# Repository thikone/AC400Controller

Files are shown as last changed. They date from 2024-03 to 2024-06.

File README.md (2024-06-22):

# AC400Controller
Replacement controller board for Record Power AC400 air filtering system.

Original board has very simplictic power supply that tends to overheat and burn that makes the use of the device hindered or not possible.

This is Arduino based drop-in replacement board that doesn't have this problem and also allows customizations.

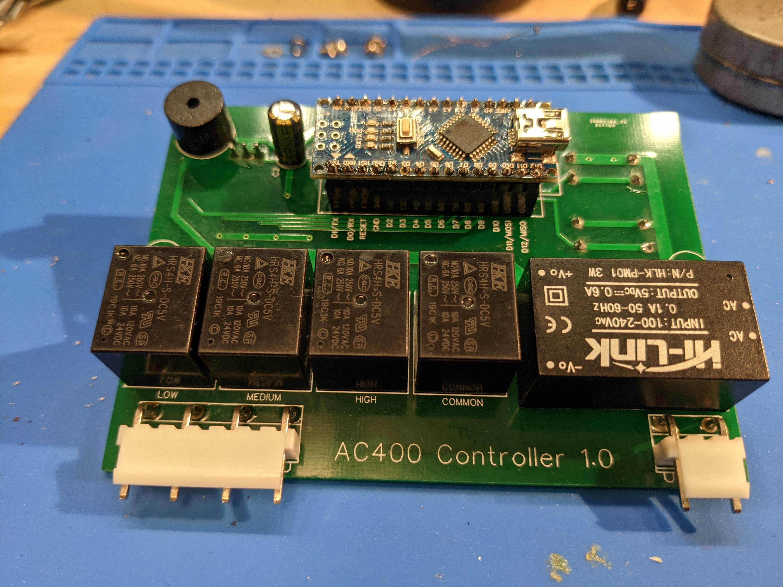
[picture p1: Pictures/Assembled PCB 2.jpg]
Assembled PCB


Ready for installation to Record Power AC400 air filtration unit:

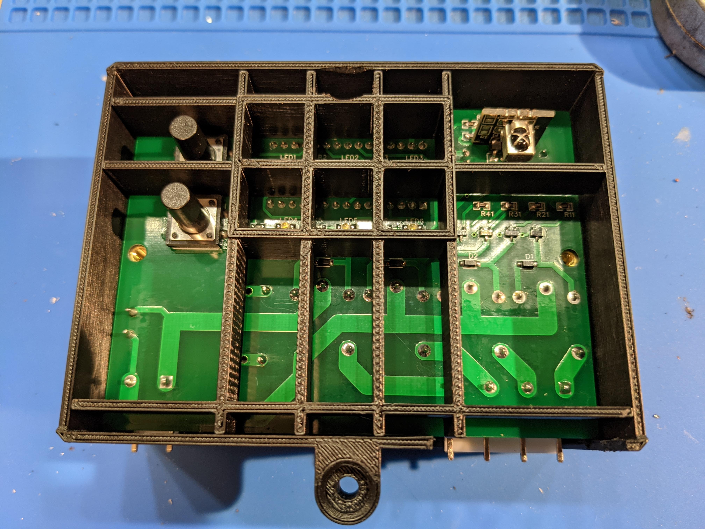
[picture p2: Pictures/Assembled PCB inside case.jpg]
Assembled PCB in the case Assembled PCB in 3D printed case


The PCB and Schematic `.json` files can be opened and viewed with EasyEDA [online](https://easyeda.com/)

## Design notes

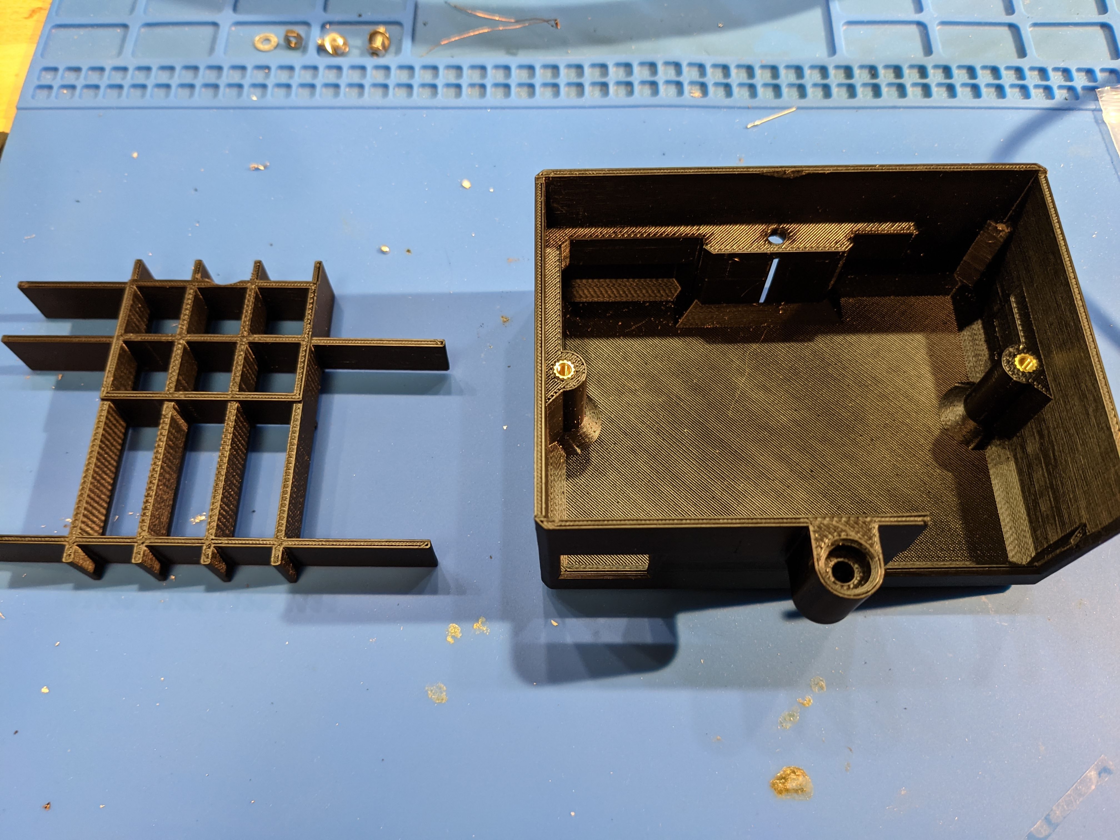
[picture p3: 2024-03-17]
Pictures/Case and grid.jpg

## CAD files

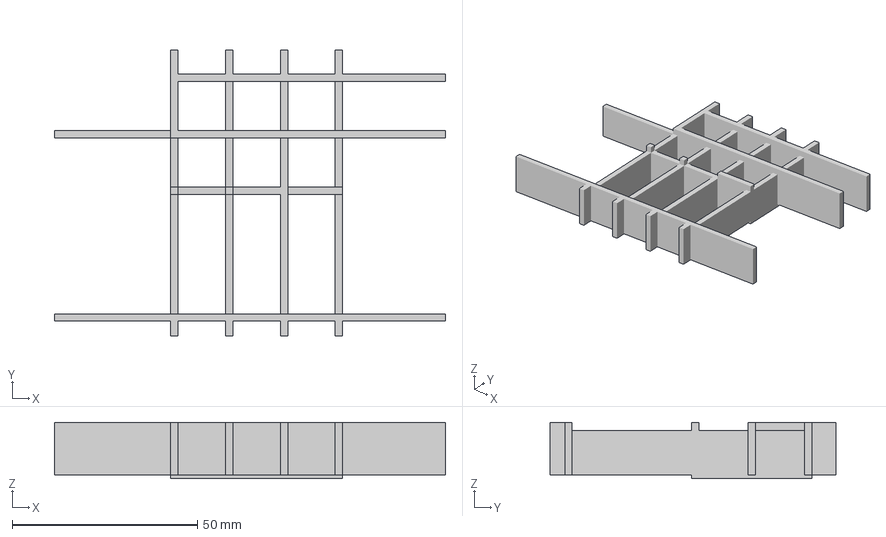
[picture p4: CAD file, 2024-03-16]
Cover/Grid v6.3mf
105.5 x 77.2 x 15.2 mm

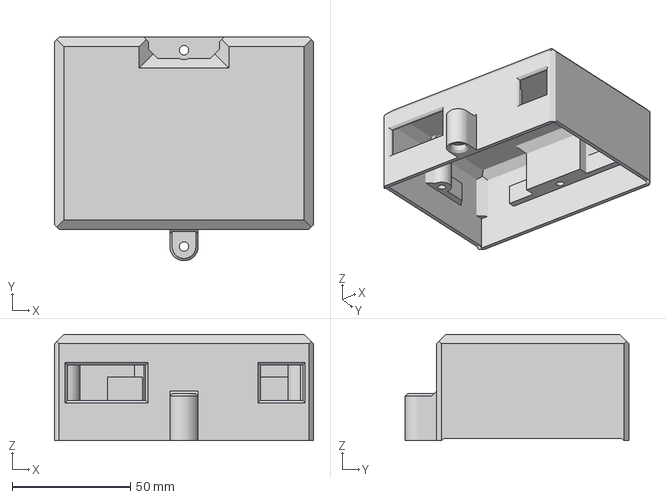
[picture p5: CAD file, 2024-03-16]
Cover/Case v6.3mf
109.5 x 94.5 x 45.0 mm

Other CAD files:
Cover/AC400 Cover v6.f3d
Cover/Case v6.stl
Cover/Grid v6.stl

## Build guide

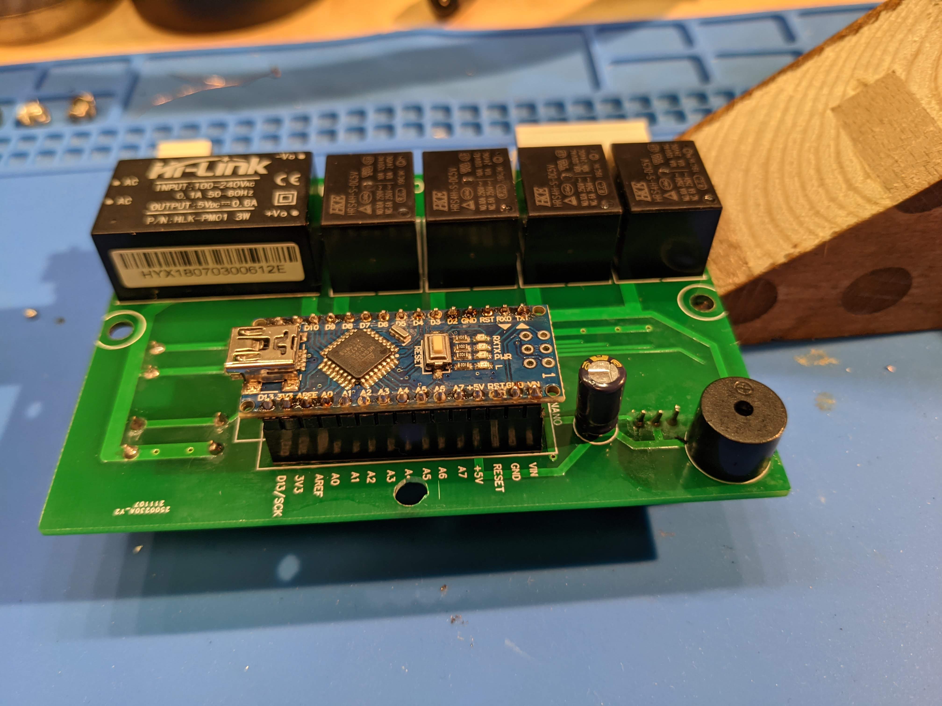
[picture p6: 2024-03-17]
Pictures/Assembled PCB 1.jpg

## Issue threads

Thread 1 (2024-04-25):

Question: Does the lack of fuse matter?

dturner, 2024-04-25:
I'm in the process of building this board and I noticed that the manufacturer's original board has a fuse next to the 240V input, this new design doesn't. Just interested to know whether it was a conscious decision to not include a fuse on this new board design?

Looking at the [specs for the machine](https://www.scosarg.com/record-ac400-2-stage-air-filter-free-delivery), the motor is 120W so at 240V that's a draw of 0.5A. Would it be worth changing the wall plug fuse to something lower, say 3A?

Slightly concerned that if a short were to occur, or the fan motor develop a fault, there could be a significant heat build up / fire risk.

thikone, 2024-04-26:
The board that came inside my machine does not have a fuse on it. The fuse is mounted on the panel and can be replaced from outside without disassembly of the unit.

I think there are several different boards that can be found in these machines. So it is totally possible that what I have might not be what you have.

So yes, there is no fuse on this replacement board. But it does make sense to have one somewhere. Perhaps you can mount it on outside panel if you don't have it there already.

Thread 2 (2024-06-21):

How to view schematic files?

matonb, 2024-06-21:
I tried uploading the the files in the schematic folder to https://www.altium.com/viewer/ but that didn't work

thikone, 2024-06-21:
Please use EasyEDA. Create a new project and open .json file.

I don't know whether Altium export of EasyEDA can be used in Altium online viewer.
EasyEDA is free and runs the browser.

Closed 2024-06-22.

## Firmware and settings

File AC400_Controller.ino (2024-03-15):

/*********************************************************************
Replacement controller board for Record Power AC400 air filtering system.

Requires:
  IRLremote (https://github.com/NicoHood/IRLremote)
Arduino standard libraries:
  EEPROM
  SoftwareSerial
*********************************************************************/

#include <IRLremote.h>

#define LED_PIN     13
#define IR_PIN       2
#define BEEP_PIN     5
#define KEY_ON_PIN   3
#define KEY_OFF_PIN  4
#define SPEED_ZERO_PIN 5
#define SPEED_LOW_PIN 6
#define SPEED_MEDIUM_PIN 7
#define SPEED_HIGH_PIN 8
#define SPEED_COMMON_PIN 9

#define LED_LOW_PIN A0
#define LED_MEDIUM_PIN A1
#define LED_HIGH_PIN A2
#define LED_ONE_PIN A5
#define LED_TWO_PIN A4
#define LED_THREE_PIN A3

#define RELAY_OFF LOW
#define RELAY_ON HIGH
#define KEY_ADDRESS 0xFF00
#define KEY_OFF_IR  0x90
#define KEY_ON_IR   0x30
#define KEY_TIME_IR 0xA0

#define SPEED_OFF 0
#define SPEED_LOW 1
#define SPEED_MEDIUM 2
#define SPEED_HIGH 3

#define AUTO_OFF 0
#define AUTO_ONE 1
#define AUTO_TWO 2
#define AUTO_THREE 3
#define AUTO_ONE_DURATION 3600000
#define AUTO_TWO_DURATION 7200000
#define AUTO_THREE_DURATION 14400000
//#define AUTO_ONE_DURATION 10000
//#define AUTO_TWO_DURATION 20000
//#define AUTO_THREE_DURATION 40000


CNec IRLremote;

int speed = SPEED_OFF;
int auto_off = AUTO_OFF;
unsigned long lastAutoTime;
unsigned long auto_delay;

int buttonState[2] = { LOW, LOW };       // the current reading from the input pin
int lastButtonState[2] = { LOW, LOW };   // the previous reading from the input pin
unsigned long lastDebounceTime[2] = { 0, 0 };  // the last time the output pin was toggled
unsigned long debounceDelay = 50;    // the debounce time; increase if the output flickers

void speedOff();

void setup()
{
  // put your setup code here, to run once:
  //Serial.begin(9600);
  //Serial.println("AC400 controller");
  IRLremote.begin(IR_PIN);
  
  pinMode(BEEP_PIN, OUTPUT);
  digitalWrite(BEEP_PIN, LOW);
  
  pinMode(KEY_ON_PIN, INPUT_PULLUP);
  pinMode(KEY_OFF_PIN, INPUT_PULLUP);

  pinMode(LED_LOW_PIN, OUTPUT);
  pinMode(LED_MEDIUM_PIN, OUTPUT);
  pinMode(LED_HIGH_PIN, OUTPUT);
  pinMode(LED_ONE_PIN, OUTPUT);
  pinMode(LED_TWO_PIN, OUTPUT);
  pinMode(LED_THREE_PIN, OUTPUT);
  
  digitalWrite(LED_LOW_PIN, LOW);
  digitalWrite(LED_MEDIUM_PIN, LOW);
  digitalWrite(LED_HIGH_PIN, LOW);
  digitalWrite(LED_ONE_PIN, LOW);
  digitalWrite(LED_TWO_PIN, LOW);
  digitalWrite(LED_THREE_PIN, LOW);

  pinMode(SPEED_LOW_PIN, OUTPUT);
  pinMode(SPEED_MEDIUM_PIN, OUTPUT);
  pinMode(SPEED_HIGH_PIN, OUTPUT);
  pinMode(SPEED_COMMON_PIN, OUTPUT);
  digitalWrite(SPEED_COMMON_PIN, RELAY_OFF);
  speedOff();
}

void beep(unsigned long duration, unsigned long pause = 0)
{
  digitalWrite(BEEP_PIN, HIGH);
  delay(duration);
  digitalWrite(BEEP_PIN, LOW);
  if(pause > 0)
    delay(pause);
}

void speedOff()
{
  digitalWrite(SPEED_LOW_PIN, RELAY_OFF);
  digitalWrite(SPEED_MEDIUM_PIN, RELAY_OFF);
  digitalWrite(SPEED_HIGH_PIN, RELAY_OFF);
}

void setSpeed(int new_speed)
{
  digitalWrite(LED_LOW_PIN, LOW);
  digitalWrite(LED_MEDIUM_PIN, LOW);
  digitalWrite(LED_HIGH_PIN, LOW);

  switch(new_speed)
  {
    case SPEED_HIGH:
      //digitalWrite(BEEP_PIN, HIGH);
      //delay(200);
      //digitalWrite(BEEP_PIN, LOW);
      //delay(100);
      beep(200, 100);
    case SPEED_MEDIUM:
      //digitalWrite(BEEP_PIN, HIGH);
      //delay(200);
      //digitalWrite(BEEP_PIN, LOW);
      //delay(100);
      beep(200, 100);
    case SPEED_LOW:
      //digitalWrite(BEEP_PIN, HIGH);
      //delay(200);
      //digitalWrite(BEEP_PIN, LOW);
      speedOff();
      beep(200);
  }
  
  speed = new_speed;
  
  digitalWrite(SPEED_COMMON_PIN, RELAY_ON);
  digitalWrite(SPEED_ZERO_PIN+speed, RELAY_ON);

  switch(speed)
  {
    case SPEED_LOW:
      digitalWrite(LED_LOW_PIN, HIGH);
      break;
    case SPEED_MEDIUM:
      digitalWrite(LED_MEDIUM_PIN, HIGH);
      break;
    case SPEED_HIGH:
      digitalWrite(LED_HIGH_PIN, HIGH);
      break;
  }
}

void setNextSpeed()
{
  int s = speed+1;
  if(s > SPEED_HIGH)
    s = SPEED_LOW;
  setSpeed(s);
}

void setSpeedOff()
{
  speed = SPEED_OFF;
  auto_off = AUTO_OFF;
  //digitalWrite(BEEP_PIN, HIGH);
  //delay(500);
  //digitalWrite(BEEP_PIN, LOW);
  beep(500);
  speedOff();
  digitalWrite(SPEED_COMMON_PIN, RELAY_OFF);
  digitalWrite(LED_LOW_PIN, LOW);
  digitalWrite(LED_MEDIUM_PIN, LOW);
  digitalWrite(LED_HIGH_PIN, LOW);
  digitalWrite(LED_ONE_PIN, LOW);
  digitalWrite(LED_TWO_PIN, LOW);
  digitalWrite(LED_THREE_PIN, LOW);
}

void setAuto(int new_auto)
{
  if(speed == SPEED_OFF)
    new_auto = AUTO_OFF;
  digitalWrite(LED_ONE_PIN, LOW);
  digitalWrite(LED_TWO_PIN, LOW);
  digitalWrite(LED_THREE_PIN, LOW);

  switch(new_auto)
  {
    case AUTO_THREE:
      //digitalWrite(BEEP_PIN, HIGH);
      //delay(50);
      //digitalWrite(BEEP_PIN, LOW);
      //delay(100);
      beep(50, 100);
      beep(200, 100);
      beep(200, 100);
      beep(200);
      break;
    case AUTO_TWO:
      //digitalWrite(BEEP_PIN, HIGH);
      //delay(50);
      //digitalWrite(BEEP_PIN, LOW);
      //delay(100);
      //beep(50, 50);
      //beep(200, 100);
      //beep(50, 50);
      //beep(200);
      beep(50, 100);
      beep(200, 100);
      beep(200);
      break;
    case AUTO_ONE:
      //digitalWrite(BEEP_PIN, HIGH);
      //delay(50);
      //digitalWrite(BEEP_PIN, LOW);
      //delay(100);
      //digitalWrite(BEEP_PIN, HIGH);
      //delay(50);
      //digitalWrite(BEEP_PIN, LOW);
      beep(50, 100);
      beep(200);
      break;
    case AUTO_OFF:
      //digitalWrite(BEEP_PIN, HIGH);
      //delay(50);
      //digitalWrite(BEEP_PIN, LOW);
      beep(50, 100);
      beep(50);
      break;
  }

  auto_off = new_auto;
  lastAutoTime = millis();
  
  switch(auto_off)
  {
    case AUTO_ONE:
      digitalWrite(LED_ONE_PIN, HIGH);
      auto_delay = AUTO_ONE_DURATION;
      break;
    case AUTO_TWO:
      digitalWrite(LED_TWO_PIN, HIGH);
      auto_delay = AUTO_TWO_DURATION;
      break;
    case AUTO_THREE:
      digitalWrite(LED_THREE_PIN, HIGH);
      auto_delay = AUTO_THREE_DURATION;
      break;
  }
  //Serial.print("Auto off at ");
  //Serial.print(auto_delay);
  //Serial.print(" current time ");
  //Serial.println(lastAutoTime);
}

void setNextAuto()
{
  int a = auto_off + 1;
  if(a > AUTO_THREE)
    a = AUTO_OFF;
  setAuto(a);
}

bool pressed(uint8_t key_pin)
{
  // read the state of the switch into a local variable:
  int reading = !digitalRead(key_pin);
  // If the switch changed, due to noise or pressing:
  if (reading != lastButtonState[key_pin - KEY_ON_PIN])
  {
    // reset the debouncing timer
    lastDebounceTime[key_pin - KEY_ON_PIN] = millis();
    // save the reading. Next time through the loop, it'll be the lastButtonState:
    lastButtonState[key_pin - KEY_ON_PIN] = reading;
    return false;
  }

  if ((millis() - lastDebounceTime[key_pin - KEY_ON_PIN]) > debounceDelay)
  {
    // whatever the reading is at, it's been there for longer than the debounce
    // delay, so take it as the actual current state:

    // if the button state has changed:
    if (reading != buttonState[key_pin - KEY_ON_PIN])
    {
      buttonState[key_pin - KEY_ON_PIN] = reading;

      // only if the new button state is HIGH
      if (buttonState[key_pin - KEY_ON_PIN] == HIGH)
      {
        return true;
      }
    }
  }
  return false;
}

void loop()
{
  if(pressed(KEY_ON_PIN))
  {
    setNextSpeed();
  }
  if(pressed(KEY_OFF_PIN))
  {
    setSpeedOff();
  }
  
  if(IRLremote.available()) // have we received an IR signal?
  {
    auto data = IRLremote.read();
    //Serial.print(data.address, HEX);
    //Serial.print(" ");
    //Serial.println(data.command, HEX);
    if(data.address == KEY_ADDRESS)
    {
      switch(data.command)
      {
        case KEY_ON_IR:
          setNextSpeed();
          break;
        case KEY_OFF_IR:
          setSpeedOff();
          break;
        case KEY_TIME_IR:
          setNextAuto();
          break;
      }
    }
  }

  if(auto_off != AUTO_OFF)
  {
    unsigned long auto_elapsed = millis() - lastAutoTime;
    if(auto_elapsed > auto_delay)
    {
      setSpeedOff();
      //Serial.print("Auto off at ");
      //Serial.print(mil);
      //Serial.print(" after waiting for ");
      //Serial.print(auto_elapsed);
      //Serial.println(" millis");
    }
    else
    {
      unsigned long auto_remaining = auto_delay - auto_elapsed;
      if(auto_off == AUTO_THREE && auto_remaining < AUTO_TWO_DURATION)
      {
        setAuto(AUTO_TWO);
      }
      else if(auto_off == AUTO_TWO && auto_remaining < AUTO_ONE_DURATION)
      {
        setAuto(AUTO_ONE);
      }
    }
  }
}

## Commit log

2024-03-15 Create SCH_AC400-Controller_2024-03-15.json
    EasyEDA schematic file.
2024-03-15 Create PCB_PCB_2022-01-01_2024-03-15.json
    EasyEDA PCB layout file.
2024-03-15 Gerber files generated by EasyEDA
2024-03-15 EasyEDA schematic export to Altium
    [Sheet_1_2024-03-15.schdoc]
2024-03-15 EasyEDA PCB export to Altium
    [PCB_2022-01-01_2024-03-15.pcbdoc]
2024-06-21 Add files via upload
    Changed base limiting current resistors from 4k7 to 100.
2024-06-22 Update README.md
    Add a line to explain how to open schematic and PCB files with EasyEDA
    Closes #2
